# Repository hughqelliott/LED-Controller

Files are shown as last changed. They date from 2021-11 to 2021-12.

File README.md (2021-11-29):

# LED Controller

ATTiny85-based single switch controller for NeoPixels.
Designed and coded for the [Pride LMC](https://hughqelliott.com/blog/pride-lmc/) project.
While the initial code is for a rainbow, the ATTiny85 can run nearly any code for NeoPixels.

### Contributions
   * Initial code and design: [Hugh Elliott](https://hughqelliott.com/blog)
   * PCB design: [Eugene Andruszczenko](https://github.com/EugeneAndruszczenko)

### Versions of code
***
   Auto-divide rainbow *will take any length strip and attempt to divide into 6 equal amounts*

### PCB design
***
   SCH and BRD files available

### STL files for handle
***
   * Main handle
   * Handle bottom
   * Trigger
   * Trigger holder

### Bill of Materials
***
   * 12X12mm Tactile switch
   * M3 Heat Set Inserts
   * M3 screws
   * M5 screws
   * 13X16.8mm Aluminum plywood edging

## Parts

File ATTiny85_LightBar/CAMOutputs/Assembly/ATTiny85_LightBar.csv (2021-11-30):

Part | Value | Device | Package | Description
C1 | 100 uF | C-USC0805 | C0805 | CAPACITOR, American symbol
R1 | 10k | R-US_R0805 | R0805 | RESISTOR, American symbol
R2 | 330 | R-US_R0805 | R0805 | RESISTOR, American symbol

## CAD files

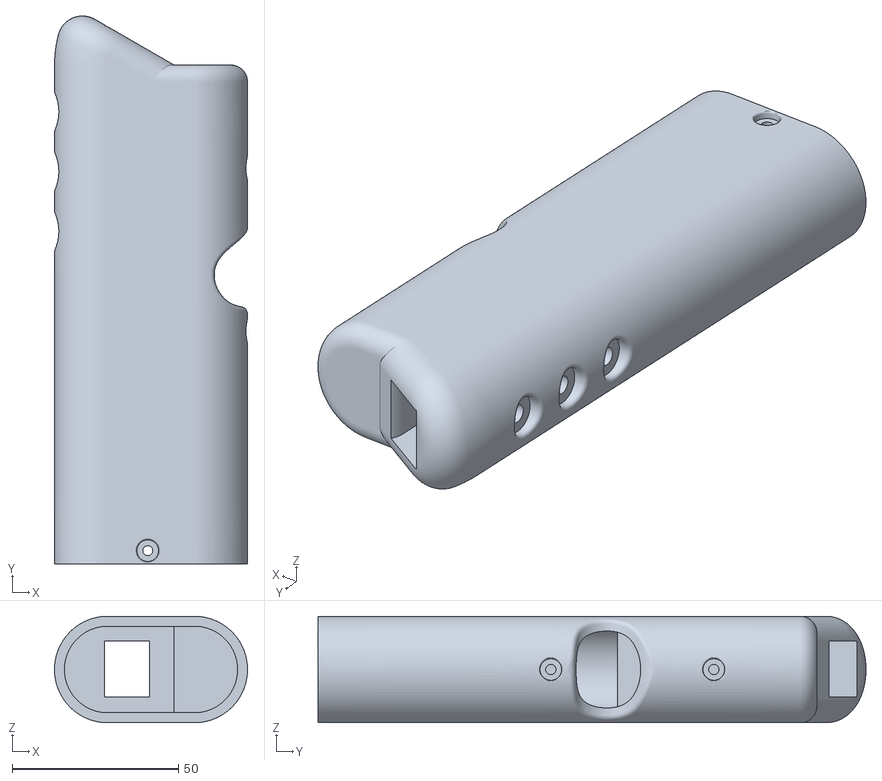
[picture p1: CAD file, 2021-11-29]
STLs/V5/V5_main.stl
58.1 x 164.7 x 32.0

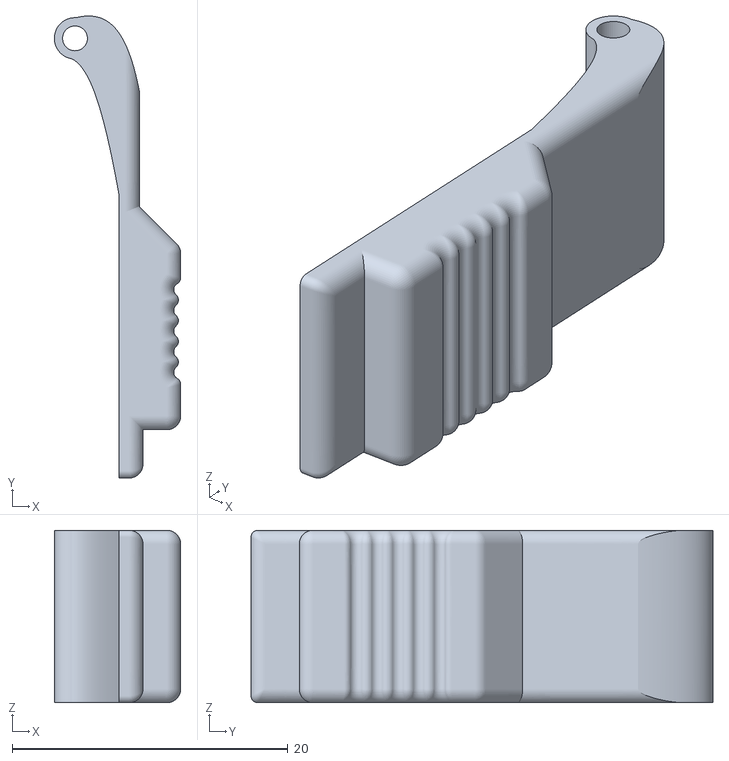
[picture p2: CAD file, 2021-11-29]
STLs/V5/V5_switch.stl
9.16 x 33.5 x 12.5

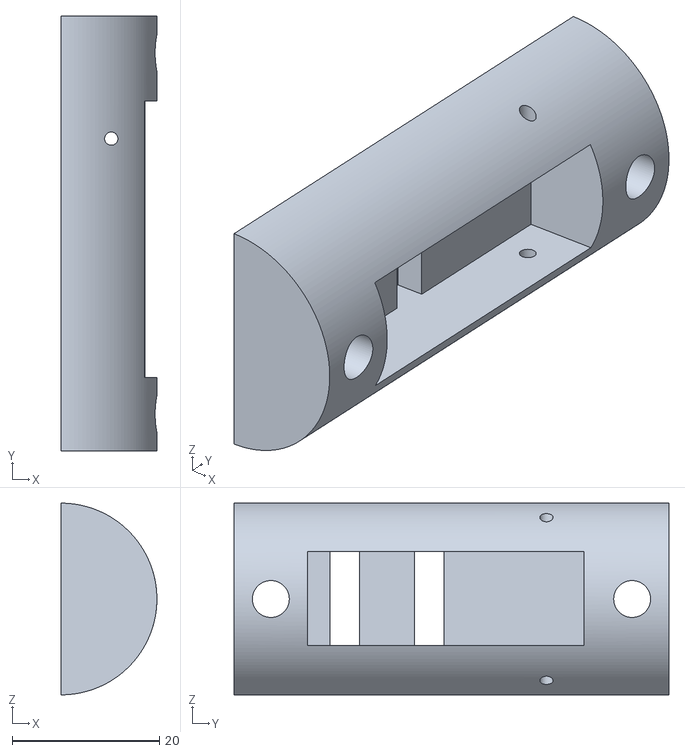
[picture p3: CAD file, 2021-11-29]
STLs/V5/V5_switchHolder.stl
13.0 x 59.0 x 26.0

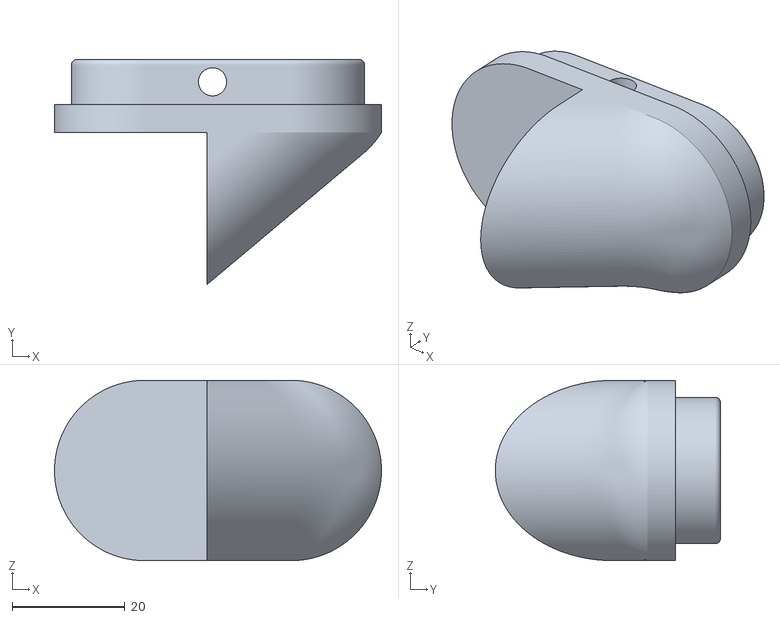
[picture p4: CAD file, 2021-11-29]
STLs/V5/V5_bottom.stl
58.1 x 40.0 x 32.0

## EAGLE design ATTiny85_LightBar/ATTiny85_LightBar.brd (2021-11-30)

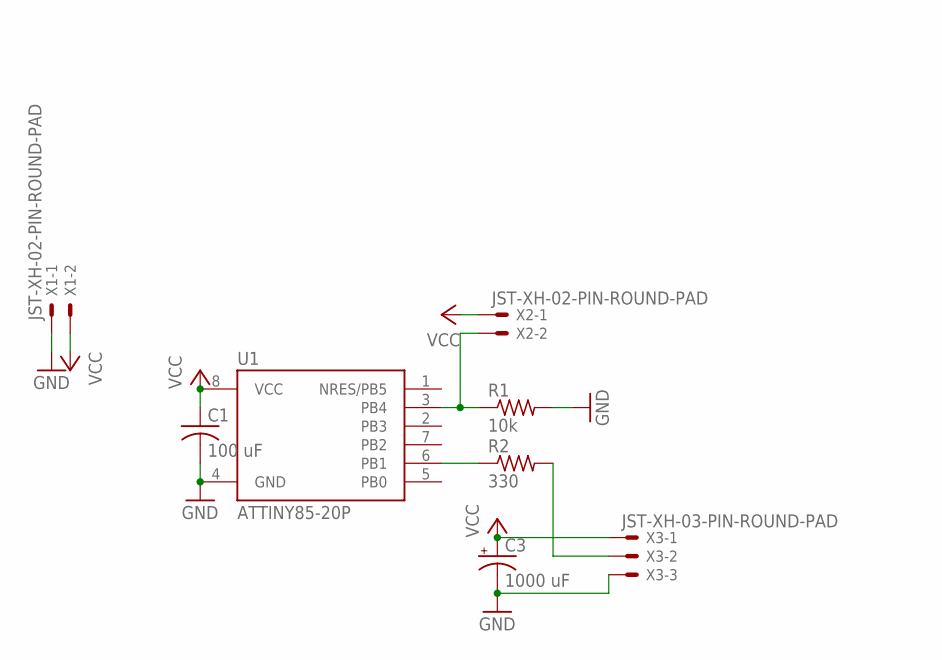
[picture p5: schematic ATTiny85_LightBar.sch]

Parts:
C1: 100 uF; C0805
C3: 1000 uF; E5-10,5
R1: 10k; R0805
R2: 330; R0805
U1: ATTINY85-20P; PDIP08_300MIL
X1, X2: JST-XH-02-PIN-ROUND-PAD; JST-XH-02-PACKAGE-ROUND-PAD
X3: JST-XH-03-PIN-ROUND-PAD; JST-XH-03-PACKAGE-ROUND-PAD

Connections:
GND: C1.2, C3.-, R1.2, U1.4 (GND), X1.1, X3.3
unnamed: R1.1, U1.3 (PB4), X2.2
unnamed: R2.1, U1.6 (PB1)
unnamed: R2.2, X3.2
VCC: C1.1, C3.+, U1.8 (VCC), X1.2, X2.1, X3.1

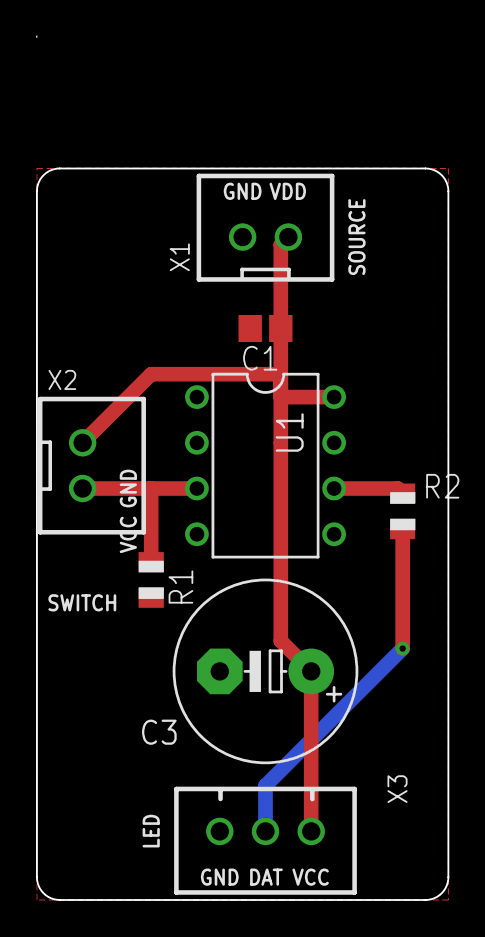
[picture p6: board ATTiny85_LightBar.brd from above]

Board: 2 copper layers, 22.9 x 40.6 mm, 8 parts (0 on the bottom side), 5 nets.

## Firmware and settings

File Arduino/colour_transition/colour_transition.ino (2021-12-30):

#include <Adafruit_NeoPixel.h> // NeoPixel library https://www.arduino.cc/en/guide/libraries
#ifdef __AVR__
 #include <avr/power.h> // Required for 16 MHz Adafruit Trinket
#endif
#define BUTTON_PIN 4 // ATTiny85 pin 4 located left side 3rd from top
#define LED_PIN 1 // ATTiny85 pin 1 located right side 3rd from top
#define LED_COUNT 60 // Number of LEDs in the strip
Adafruit_NeoPixel strip(LED_COUNT, LED_PIN, NEO_GRB + NEO_KHZ800); // Declare the strip

/*----------
Colour values with named colours for ease of use
when making your own you can change these colours as you like or make new ones.
----------*/
const auto red    =   Adafruit_NeoPixel::Color(255, 0, 0);
const auto orange =   Adafruit_NeoPixel::Color(235,45,0);
const auto yellow =   Adafruit_NeoPixel::Color(180,100,0);
const auto green  =   Adafruit_NeoPixel::Color(0,255,20);
const auto blue   =   Adafruit_NeoPixel::Color(0,40,255);
const auto purple =   Adafruit_NeoPixel::Color(100,0,255);
const auto white  =   Adafruit_NeoPixel::Color(50,50,50);
const auto black  =   Adafruit_NeoPixel::Color(0,0,0);

int colourCycle = 0; // click through available colours
int cycleMax = 7; // maximum number of colours
unsigned long buttonWaitAmnt = 0; // time in milliseconds to wait to check the loop

unsigned long buttonAmnt = 100; // delay in milliseconds to add to the check

void setup() {
  delay(1000); // give the ATTiny85 time to power up
  #if defined(__AVR_ATtiny85__) && (F_CPU == 16000000)
  clock_prescale_set(clock_div_1); //the ATTiny85 clock is 16mHz
#endif
  delay(1000); // one more second wait
  setButtonPause(); //initialize the check
  pinMode(BUTTON_PIN,INPUT);  // set the tactile switch pin to input. 
                              // This pin has a 10K pulldown resistor connected to ground. 
                              // The switch is connected to +5V between the resistor and pin.
                              // Switch pulls the pin HIGH when clicked.
  strip.begin(); // initialize the NeoPixel strip
  setStripColour(white); // solid colour to entire strip with a short delay
  delay(100);
  setStripColour(red);
  delay(100);
  setStripColour(orange);
  delay(100);
  setStripColour(yellow);
  delay(100);
  setStripColour(green);
  delay(100);
  setStripColour(blue);
  delay(100);
  setStripColour(purple);
  delay(100);
  setStripColour(black); // turn off the strip
}

/*----------
setButtonPause function - no arguments passed
  reset the wait time buttonWaitAmnt, in milliseconds millis()
  by adding the delay buttonAmnt
----------*/
void setButtonPause(){
    buttonWaitAmnt = millis() + buttonAmnt;
}
/*----------
setStripColour function - colour argument in plain text as long as declared above
  sets the colour for the entire strip
  otherwise can call with a different colour using strip.color(r,g,b); 
  r,g,b values between 0-255
----------*/
void setStripColour(uint32_t colour){
    for(int i=0; i<LED_COUNT; i++) {
    strip.setPixelColor(i, colour);
    }
    strip.show();
}
int increment = 0;
int incrementmax = 30; //number of increments needed to get from one colour to another
void changeStripColour(int startr, int endr, int startg, int endg, int startb, int endb){
  int r = map(increment, 0,incrementmax,startr,endr);
  int g = map(increment, 0,incrementmax,startg,endg);
  int b = map(increment, 0,incrementmax,startb,endb);
  uint32_t currentColour = Adafruit_NeoPixel::Color(r, g, b);
  setStripColour(currentColour);
}
boolean checkState = false; // switch on off if off set to false if on set to true
void loop() {
    if(millis() > buttonWaitAmnt){ // check wait
  int buttonState = digitalRead(BUTTON_PIN); // get switch state
  if(buttonState == HIGH){ // if switch pressed
    checkState = true; // we know the switch is pressed. 
    switch(colourCycle){
      case 0:
      changeStripColour(0,50,0,50,0,50);
      break;
      case 1:
      changeStripColour(50,255,50,0,50,0);
      break;
      case 2:
      changeStripColour(255,235,0,45,50,0);
      break;
      case 3:
      changeStripColour(235,180,45,100,0,0);
      break;
      case 4:
      changeStripColour(180,0,45,255,0,20);
      break;
      case 5:
      changeStripColour(0,0,255,40,20,255);
      break;
      case 6:
      changeStripColour(0,100,40,0,255,255);
      break;
      case 7:
      changeStripColour(100,0,0,0,255,0);
      break;
    }
    if(increment < incrementmax){
      increment++;
    }
  }else if(buttonState == LOW && checkState){ // if switch released and we didn't know
    checkState = false; // we know the switch is released. avoids double calls
    if(colourCycle<cycleMax){
      colourCycle++;
    }else{
      colourCycle = 0;
    }
    increment = 0; //reset the transition increment
  setStripColour(black); // turn off strip
  }
  setButtonPause(); // reset the timer
    }
}

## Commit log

2021-11-29 V5 light bar 3D printed parts
    [V5_bottom.stl, V5_main.stl, V5_switch.stl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]
2021-11-29 remove ng in stl list
2021-11-30 additional files for board, cycling code for arduino
    [ATTiny85_LightBar.brd, ATTiny85_LightBar.sch]
2021-11-30 updating corrected files for PCB
    [ATTiny85_LightBar.brd, ATTiny85_LightBar.csv, ATTiny85_LightBar.sch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]
2021-12-30 Illustrator file of the basic circuit
